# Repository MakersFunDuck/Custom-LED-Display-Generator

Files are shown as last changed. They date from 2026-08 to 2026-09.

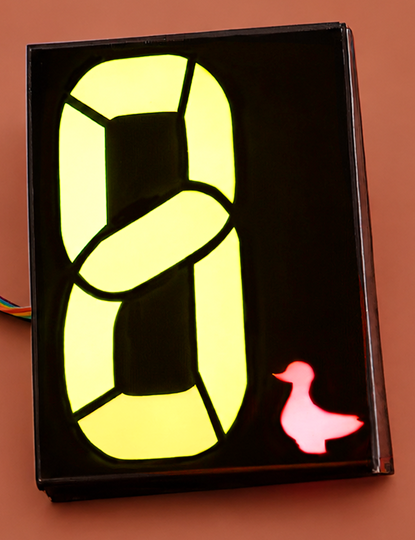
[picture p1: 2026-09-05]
preview2.png

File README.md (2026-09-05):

# Custom LED Display Generator
A Python-based tool for designing and generating custom LED displays from a single image file.  The goal of this project is to make it easier for electronics hobbyists and makers to create their own custom LED displays without having to manually design the mechanical, graphical, and electronic parts separately.  You define your display and select the required MCU and LED-driving configuration, and the tool generates the files needed to build it.

You may find detailed usage instructions in the video:
https://youtu.be/lEBiFov_C0w

# Installation and Usage

Steps
1. Install Python 3.12

Download from:

Python 3.12 Downloads

https://www.python.org/downloads/release/python-3120/

During install:

check "Add Python to PATH"

Check the active python version
```python -V```

Setup and Run
2. Create a virtual environment

Create a virtual environment named .venv:

```python -m venv .venv```

3. Activate the virtual environment
PowerShell
```.\.venv\Scripts\Activate```

Command Prompt (cmd)
```.\.venv\Scripts\activate.bat```

4. Confirm Python and pip point to the virtual environment
```python -V```
```python -m pip --version```

5. Upgrade pip

Upgrade pip, setuptools, and wheel inside the virtual environment:

```python -m pip install --upgrade pip setuptools wheel```

6. Install dependencies

Install the required Python packages:

```python -m pip install -r requirements.txt```

7. Start the app
```python main.py```

![Preview](preview.png?raw=true "preview")
![Preview](preview2.png?raw=true "preview")

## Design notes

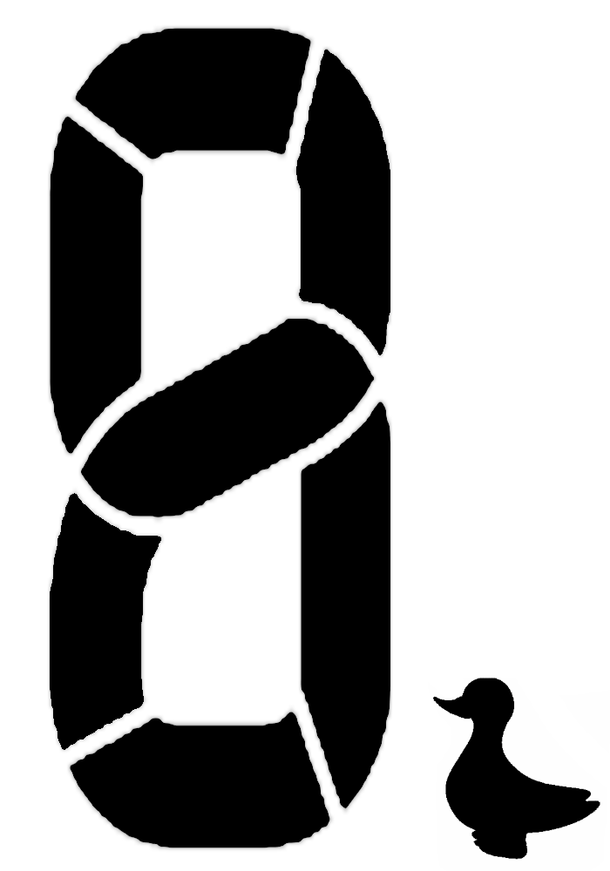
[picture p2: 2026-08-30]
7DigitCustom.png

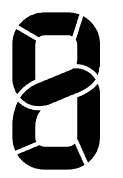
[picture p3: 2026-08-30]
ugly.png

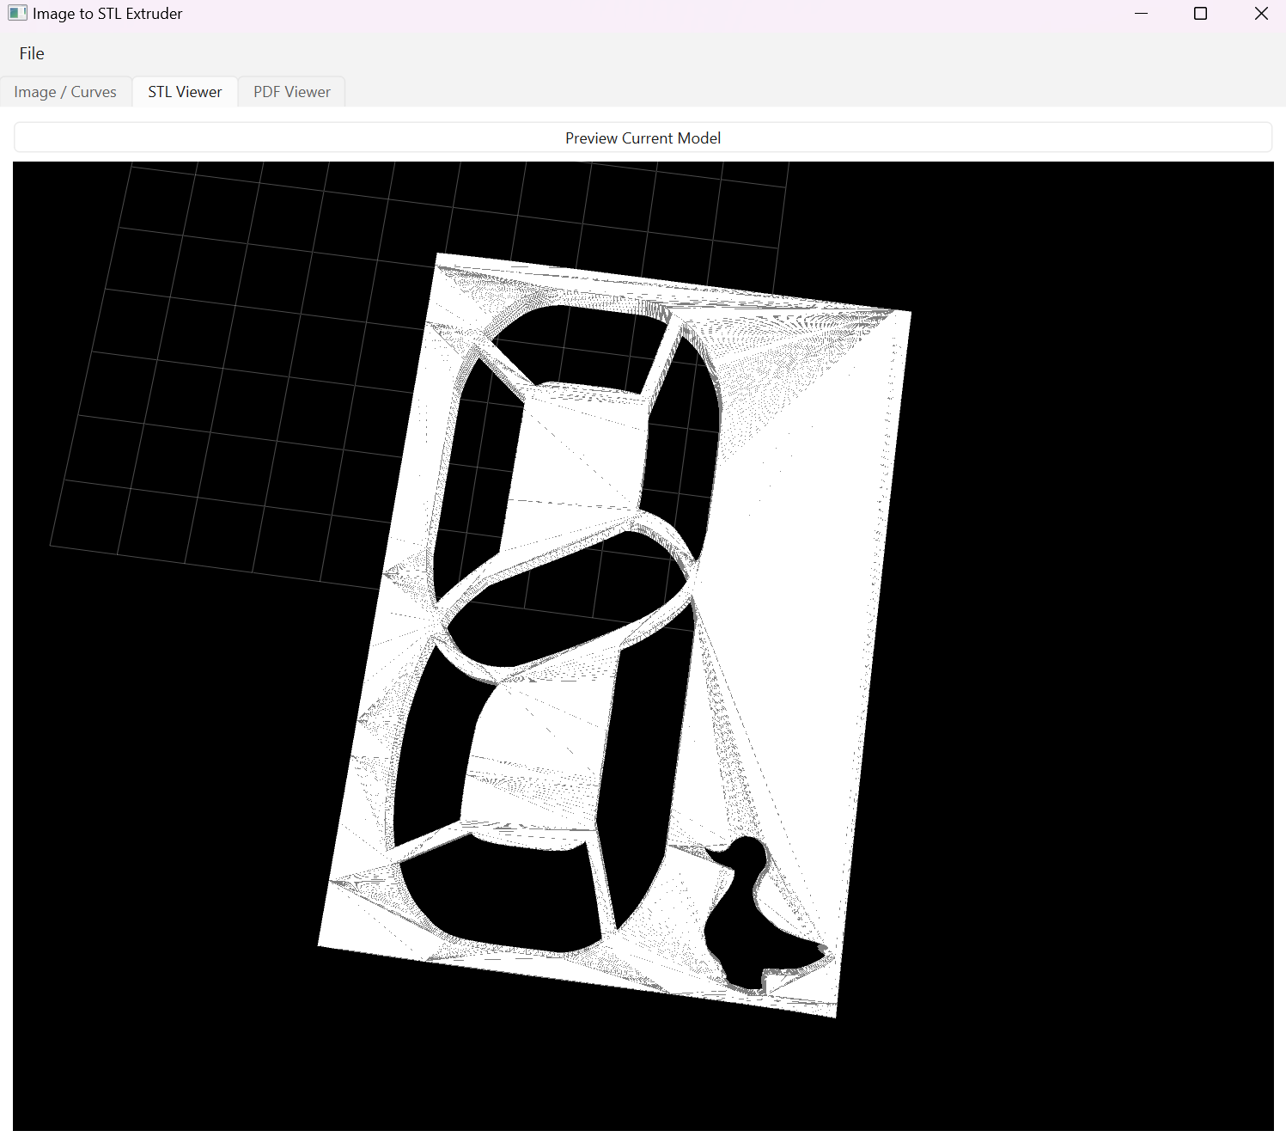
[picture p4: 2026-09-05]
preview.png

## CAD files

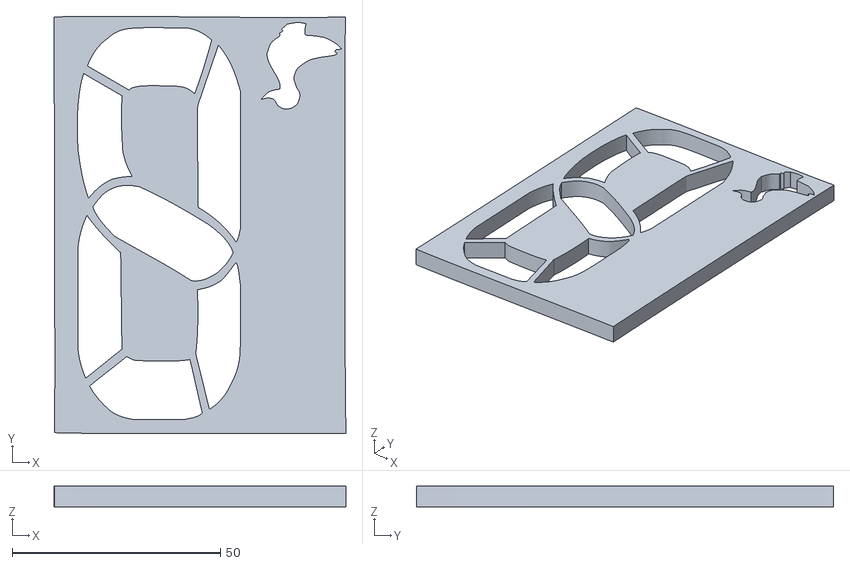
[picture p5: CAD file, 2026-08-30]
7DigitCustom/7DigitCustom_3d_model.stl
70.1 x 100.1 x 5.00

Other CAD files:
Unnamed.FCStd
7DigitCustom/7DigitCustom_3d_model_edited.stl
7DigitCustom_3d_model.stl
backups/7DigitCustom_3d_model.stl

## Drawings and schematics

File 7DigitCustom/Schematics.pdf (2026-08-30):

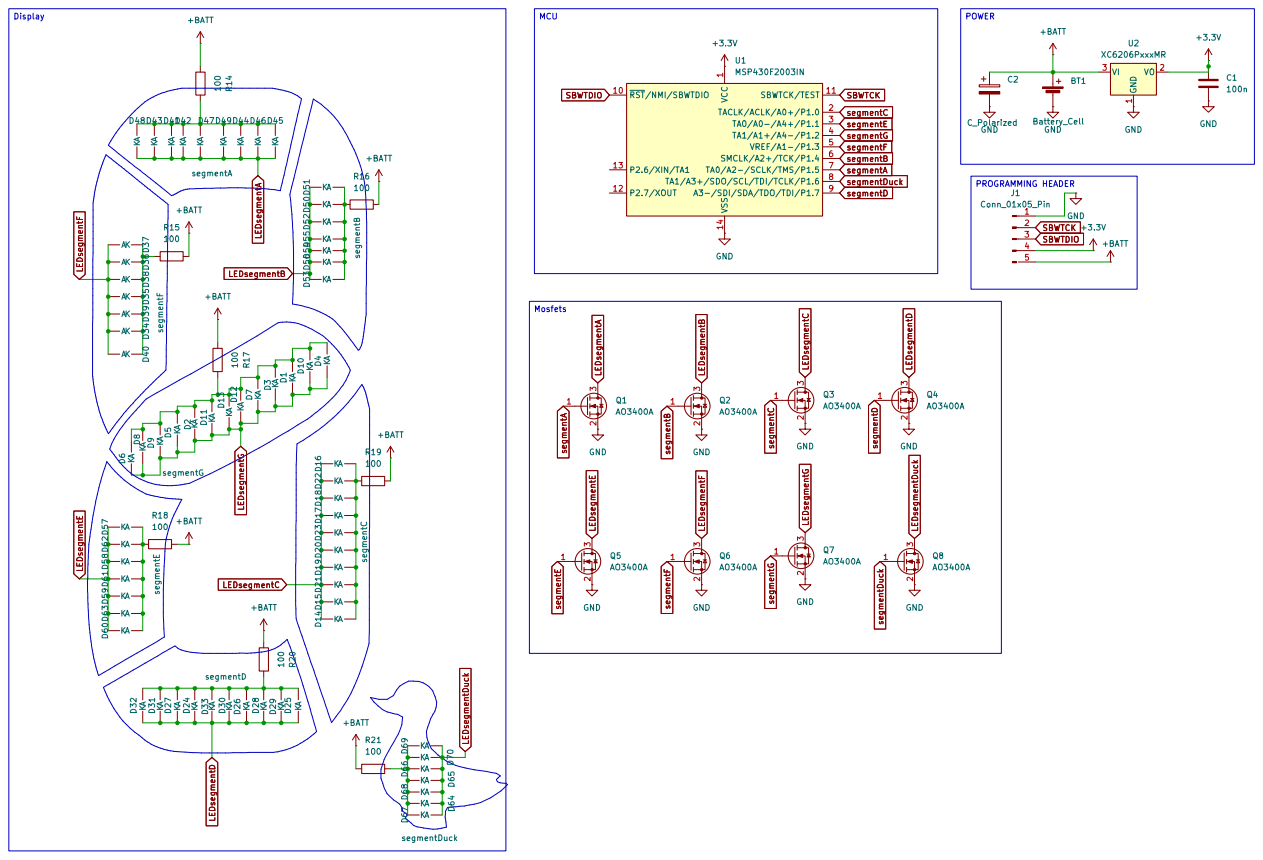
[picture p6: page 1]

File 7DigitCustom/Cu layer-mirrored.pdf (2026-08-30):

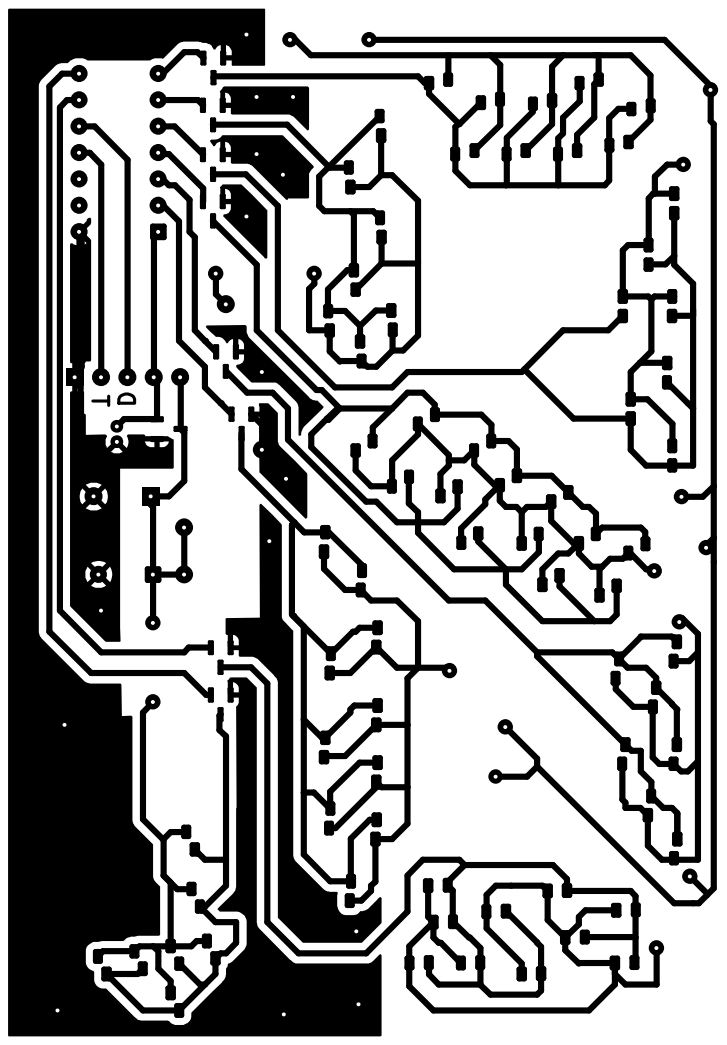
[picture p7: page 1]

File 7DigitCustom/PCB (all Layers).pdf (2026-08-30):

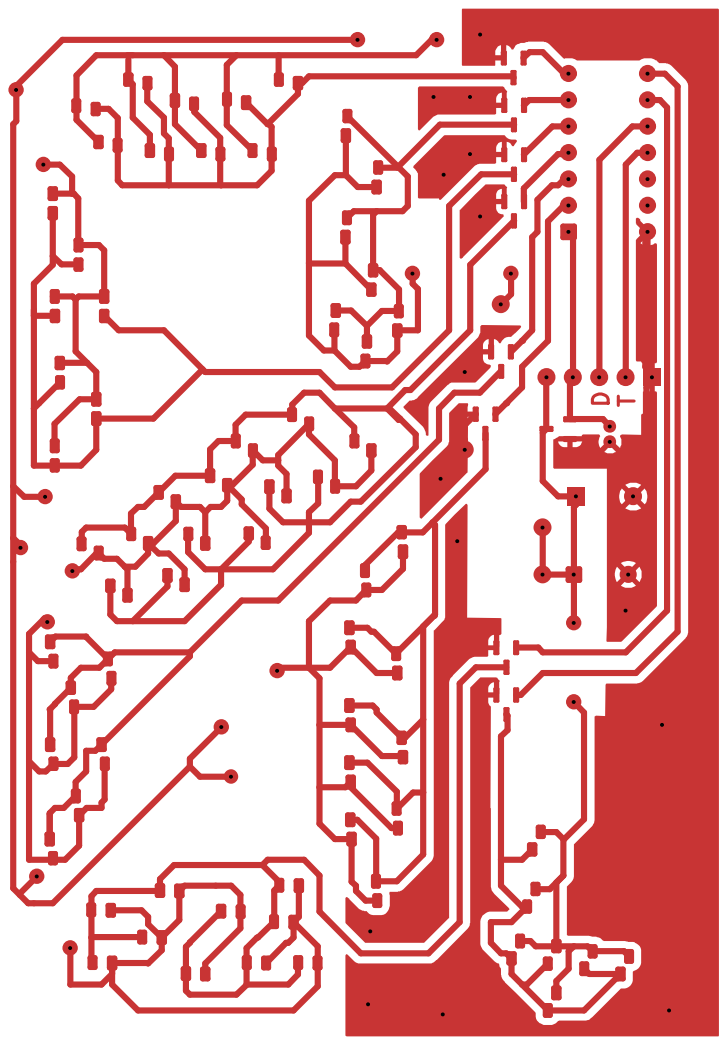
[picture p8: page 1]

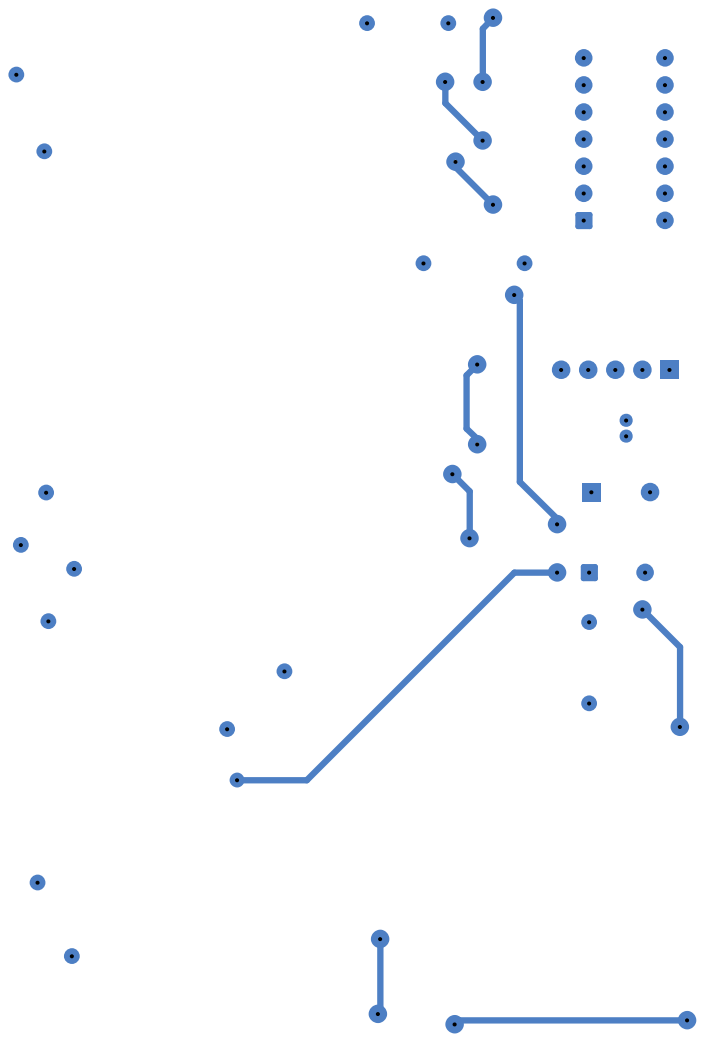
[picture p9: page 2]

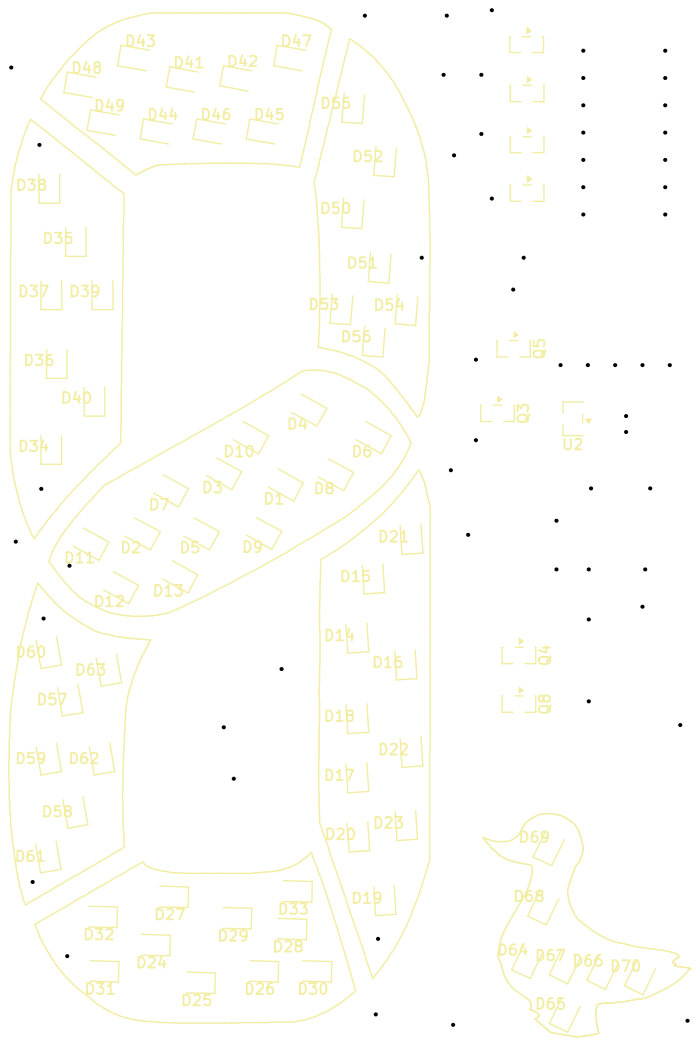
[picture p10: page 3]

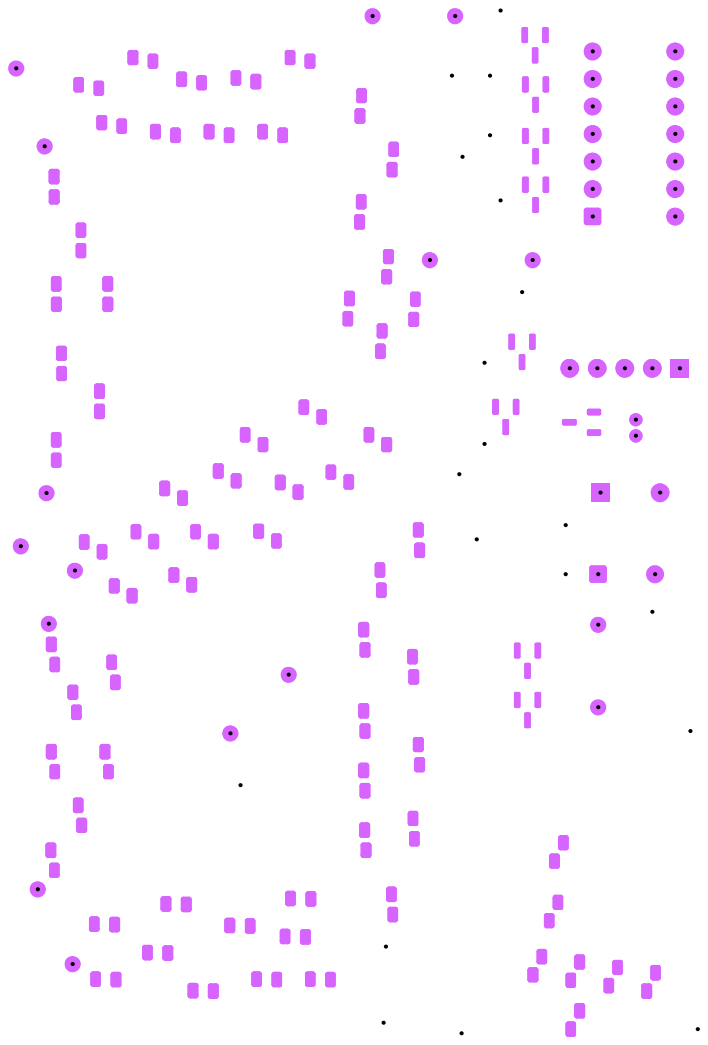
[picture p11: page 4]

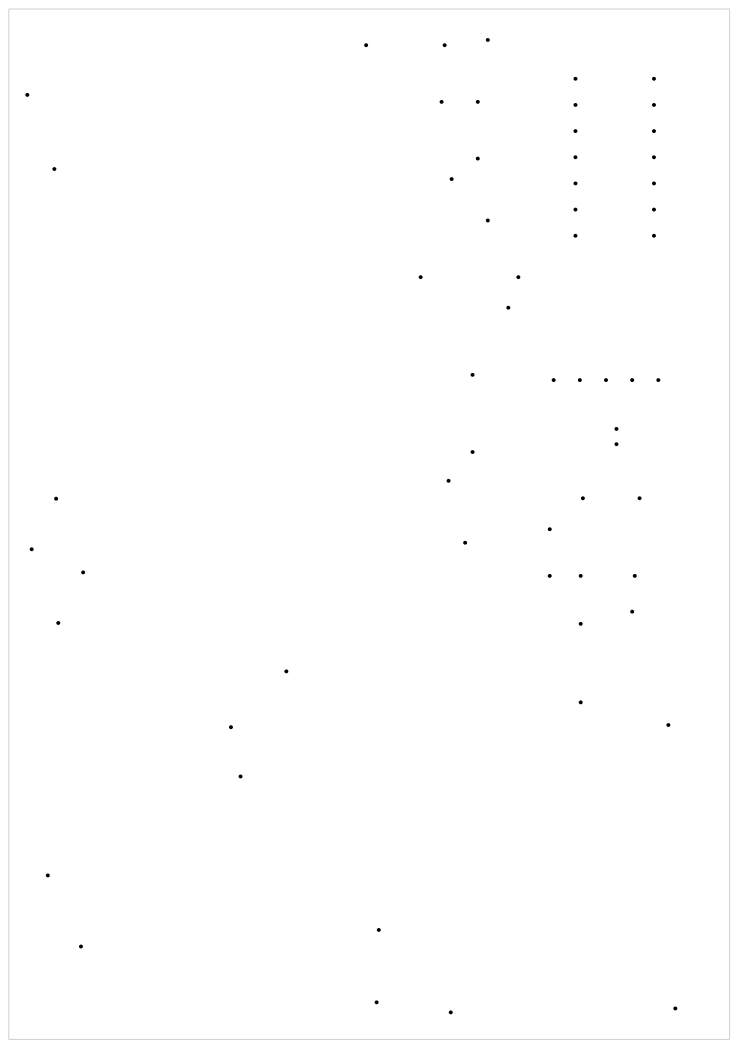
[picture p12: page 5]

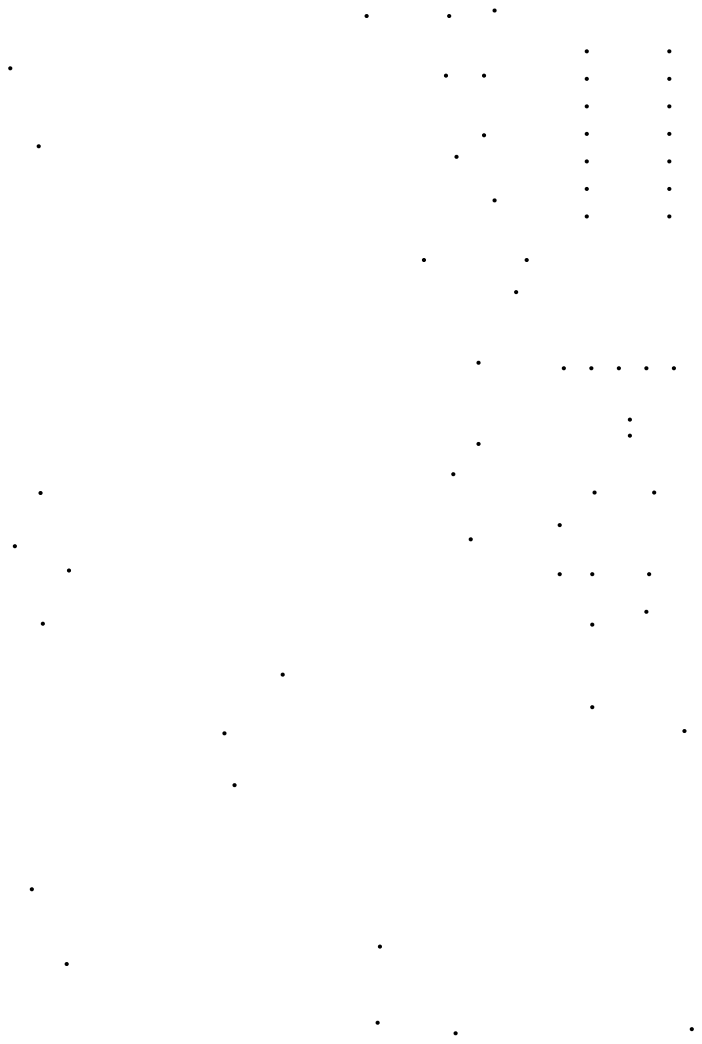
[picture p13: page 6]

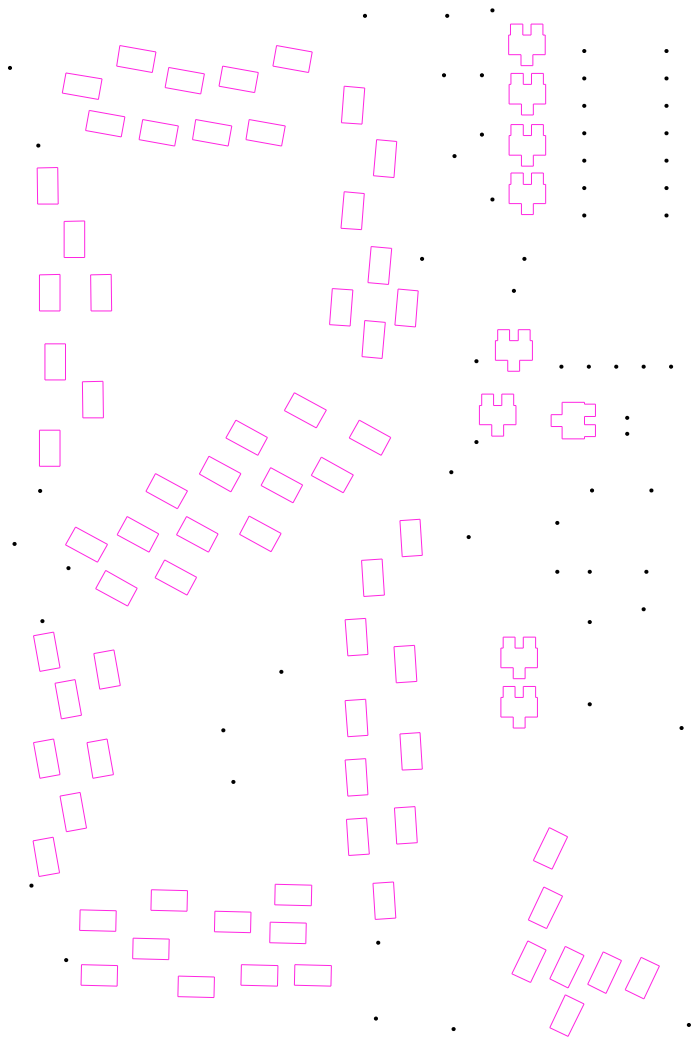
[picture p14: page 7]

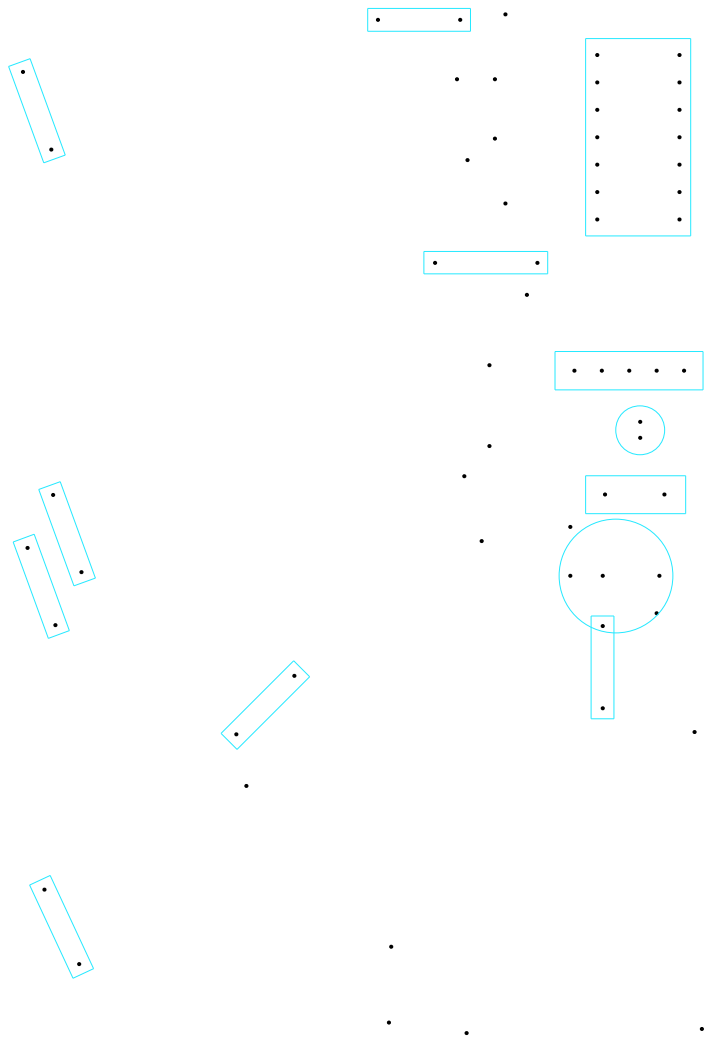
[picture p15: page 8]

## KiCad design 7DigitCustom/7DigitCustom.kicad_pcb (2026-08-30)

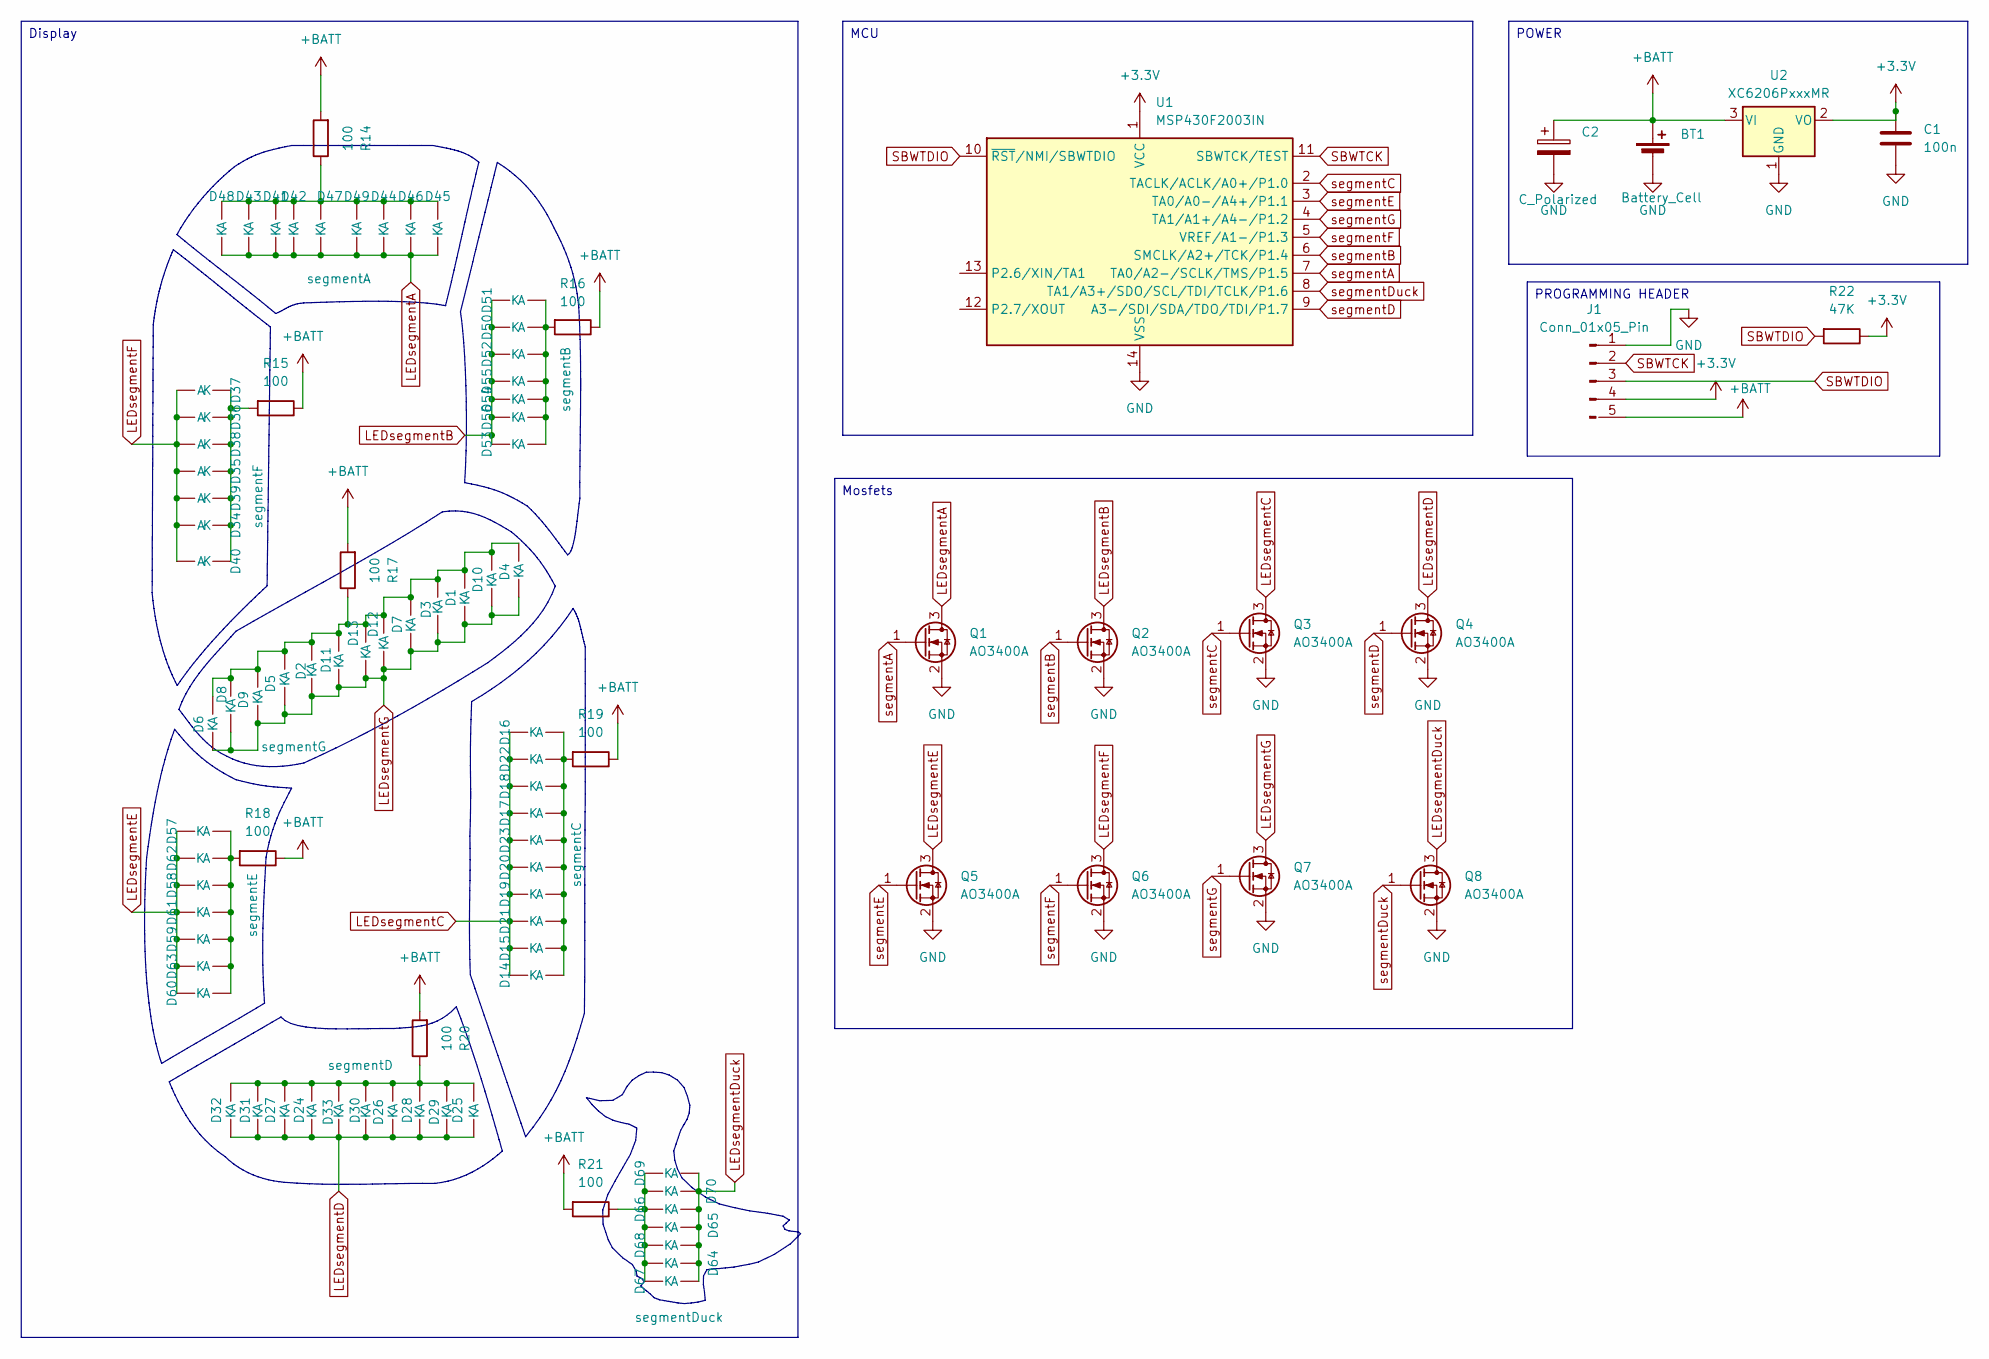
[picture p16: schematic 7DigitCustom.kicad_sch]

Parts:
BT1: Battery_Cell; PinHeader_1x02_P2.54mm_Vertical
C1: 100n; C_Radial_D4.0mm_H7.0mm_P1.50mm
C2: C_Polarized; CP_Radial_D10.0mm_P2.50mm
D1, D2, D3, D4, D5, D6, D7, D8, D9, D10, D11, D12, D13: segmentG; LED_0805_2012Metric
D14, D15, D16, D17, D18, D19, D20, D21, D22, D23: segmentC; LED_0805_2012Metric
D24, D25, D26, D27, D28, D29, D30, D31, D32, D33: segmentD; LED_0805_2012Metric
D34, D35, D36, D37, D38, D39, D40: segmentF; LED_0805_2012Metric
D41, D42, D43, D44, D45, D46, D47, D48, D49: segmentA; LED_0805_2012Metric
D50, D51, D52, D53, D54, D55, D56: segmentB; LED_0805_2012Metric
D57, D58, D59, D60, D61, D62, D63: segmentE; LED_0805_2012Metric
D64, D65, D66, D67, D68, D69, D70: segmentDuck; LED_0805_2012Metric
J1: Conn_01x05_Pin; PinHeader_1x05_P2.54mm_Vertical
Q1, Q2, Q3, Q4, Q5, Q6, Q7, Q8: AO3400A; SOT-23
R14, R15, R16, R17, R18, R19, R20, R21: 100; R_Axial_DIN0204_L3.6mm_D1.6mm_P7.62mm_Horizontal
R22: 47K; R_Axial_DIN0204_L3.6mm_D1.6mm_P7.62mm_Horizontal
U1: MSP430F2003IN; DIP-14_W7.62mm
U2: XC6206PxxxMR; SOT-23-3

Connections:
+3.3V: C1.1, J1.4, R22.1, U1.1 (VCC), U2.2 (VO)
+BATT: BT1.1 (+), C2.1, J1.5 (Pin_4), R14.2, R15.1, R16.1, R17.2, R18.1, R19.1, R20.2, R21.2, U2.3 (VI)
GND: BT1.2 (-), C1.2, C2.2, J1.1, Q1.2 (S), Q2.2 (S), Q3.2 (S), Q4.2 (S), Q5.2 (S), Q6.2 (S), Q7.2 (S), Q8.2 (S), U1.14 (VSS), U2.1 (GND)
LEDsegmentA: D41.2 (A), D42.2 (A), D43.2 (A), D44.2 (A), D45.2 (A), D46.2 (A), D47.2 (A), D48.2 (A), D49.2 (A), Q1.3 (D)
LEDsegmentB: D50.2 (A), D51.2 (A), D52.2 (A), D53.2 (A), D54.2 (A), D55.2 (A), D56.2 (A), Q2.3 (D)
LEDsegmentC: D14.2 (A), D15.2 (A), D16.2 (A), D17.2 (A), D18.2 (A), D19.2 (A), D20.2 (A), D21.2 (A), D22.2 (A), D23.2 (A), Q3.3 (D)
LEDsegmentD: D24.2 (A), D25.2 (A), D26.2 (A), D27.2 (A), D28.2 (A), D29.2 (A), D30.2 (A), D31.2 (A), D32.2 (A), D33.2 (A), Q4.3 (D)
LEDsegmentDuck: D64.1 (K), D65.1 (K), D66.1 (K), D67.1 (K), D68.1 (K), D69.1 (K), D70.1 (K), Q8.3 (D)
LEDsegmentE: D57.2 (A), D58.2 (A), D59.2 (A), D60.2 (A), D61.2 (A), D62.2 (A), D63.2 (A), Q5.3 (D)
LEDsegmentF: D34.1 (K), D35.1 (K), D36.1 (K), D37.1 (K), D38.1 (K), D39.1 (K), D40.1 (K), Q6.3 (D)
LEDsegmentG: D1.2 (A), D2.2 (A), D3.2 (A), D4.2 (A), D5.2 (A), D6.2 (A), D7.2 (A), D8.2 (A), D9.2 (A), D10.2 (A), D11.2 (A), D12.2 (A), D13.2 (A), Q7.3 (D)
unnamed: D1.1 (K), D2.1 (K), D3.1 (K), D4.1 (K), D5.1 (K), D6.1 (K), D7.1 (K), D8.1 (K), D9.1 (K), D10.1 (K), D11.1 (K), D12.1 (K), D13.1 (K), R17.1
unnamed: D14.1 (K), D15.1 (K), D16.1 (K), D17.1 (K), D18.1 (K), D19.1 (K), D20.1 (K), D21.1 (K), D22.1 (K), D23.1 (K), R19.2
unnamed: D24.1 (K), D25.1 (K), D26.1 (K), D27.1 (K), D28.1 (K), D29.1 (K), D30.1 (K), D31.1 (K), D32.1 (K), D33.1 (K), R20.1
unnamed: D34.2 (A), D35.2 (A), D36.2 (A), D37.2 (A), D38.2 (A), D39.2 (A), D40.2 (A), R15.2
unnamed: D41.1 (K), D42.1 (K), D43.1 (K), D44.1 (K), D45.1 (K), D46.1 (K), D47.1 (K), D48.1 (K), D49.1 (K), R14.1
unnamed: D50.1 (K), D51.1 (K), D52.1 (K), D53.1 (K), D54.1 (K), D55.1 (K), D56.1 (K), R16.2
unnamed: D57.1 (K), D58.1 (K), D59.1 (K), D60.1 (K), D61.1 (K), D62.1 (K), D63.1 (K), R18.2
unnamed: D64.2 (A), D65.2 (A), D66.2 (A), D67.2 (A), D68.2 (A), D69.2 (A), D70.2 (A), R21.1
SBWTCK: J1.2, U1.11 (SBWTCK/TEST)
SBWTDIO: J1.3, R22.2, U1.10 (~RST/NMI/SBWTDIO)
segmentA: Q1.1 (G), U1.7 (TA0/A2-/SCLK/TMS/P1.5)
segmentB: Q2.1 (G), U1.6 (SMCLK/A2+/TCK/P1.4)
segmentC: Q3.1 (G), U1.2 (TACLK/ACLK/A0+/P1.0)
segmentD: Q4.1 (G), U1.9 (A3-/SDI/SDA/TDO/TDI/P1.7)
segmentDuck: Q8.1 (G), U1.8 (TA1/A3+/SDO/SCL/TDI/TCLK/P1.6)
segmentE: Q5.1 (G), U1.3 (TA0/A0-/A4+/P1.1)
segmentF: Q6.1 (G), U1.5 (VREF/A1-/P1.3)
segmentG: Q7.1 (G), U1.4 (TA1/A1+/A4-/P1.2)

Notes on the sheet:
Display
PROGRAMMING HEADER
MCU
Mosfets
POWER

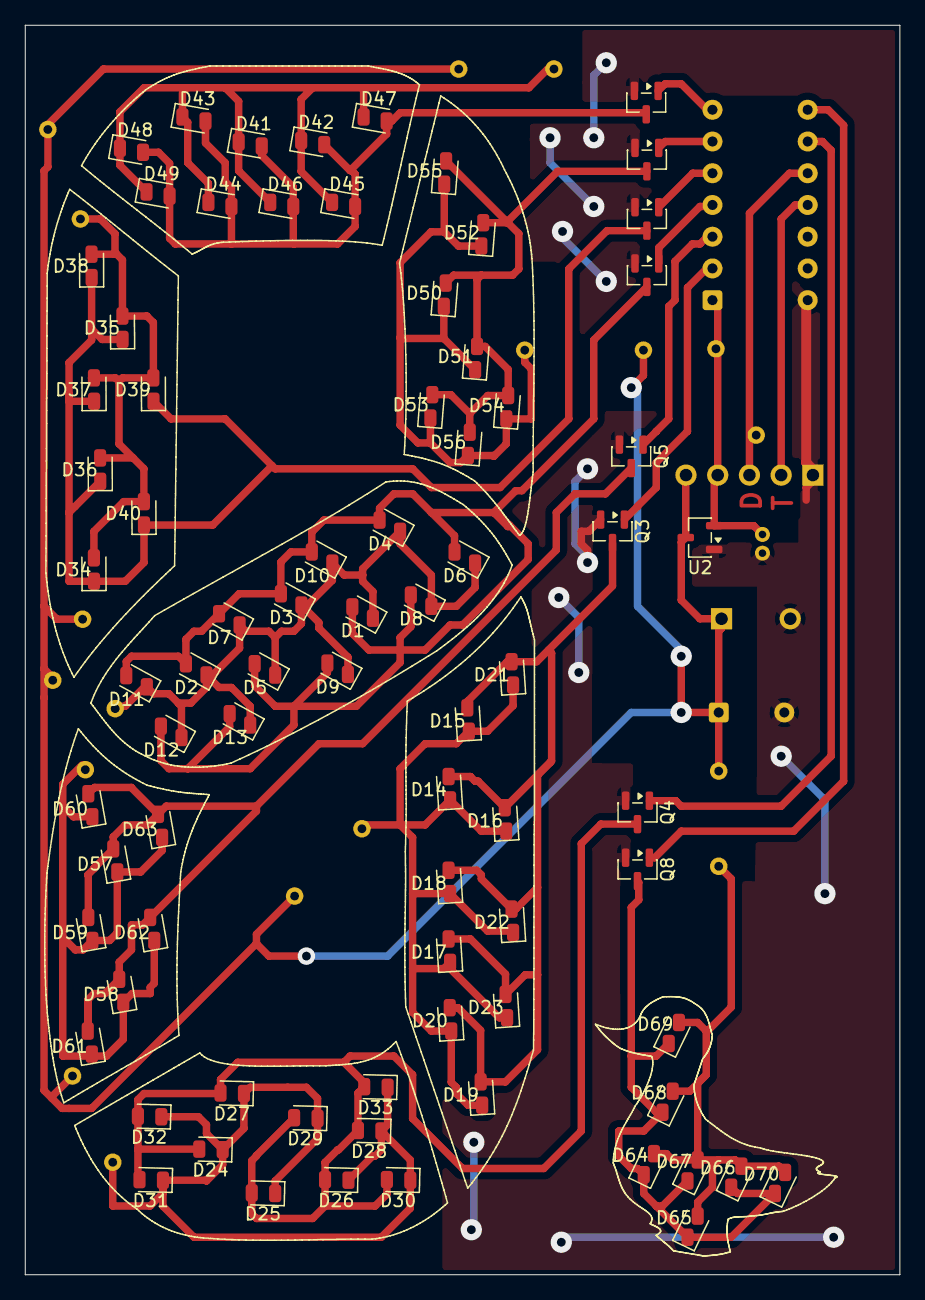
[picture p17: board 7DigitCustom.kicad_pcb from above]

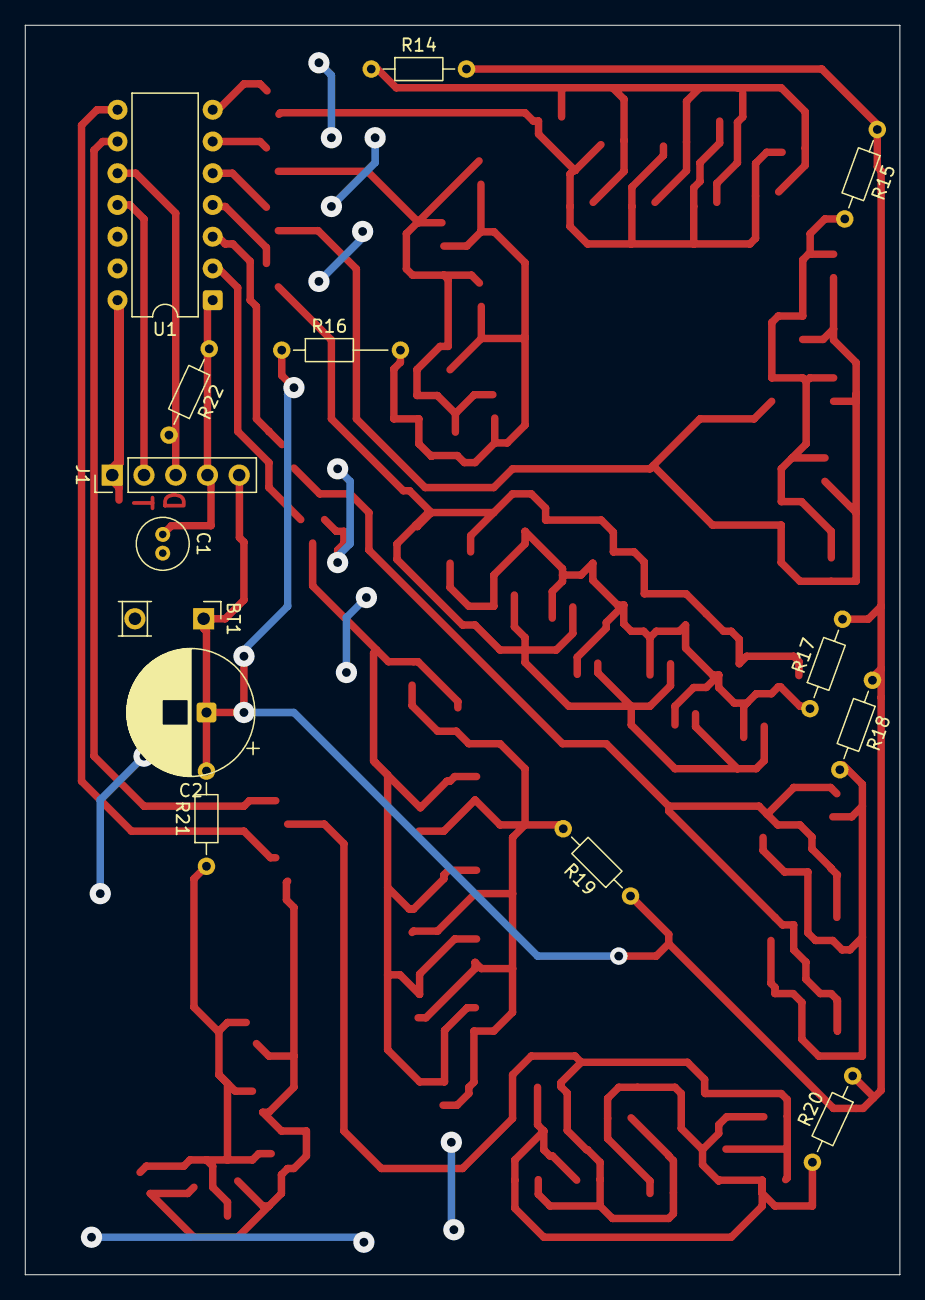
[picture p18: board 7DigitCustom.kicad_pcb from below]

Board: 2 copper layers, 70.0 x 100.0 mm, 93 parts (14 on the bottom side), 29 nets.
